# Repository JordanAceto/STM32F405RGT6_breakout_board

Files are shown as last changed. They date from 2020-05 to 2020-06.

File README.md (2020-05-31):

# Breakout board for STM32F405

## The goals of this project in no particular order:
- Get my feet wet with 4-layer pcb layout
- Try out the jlcpcb assembly service
- Get a few extra stm32 boards to experiment with

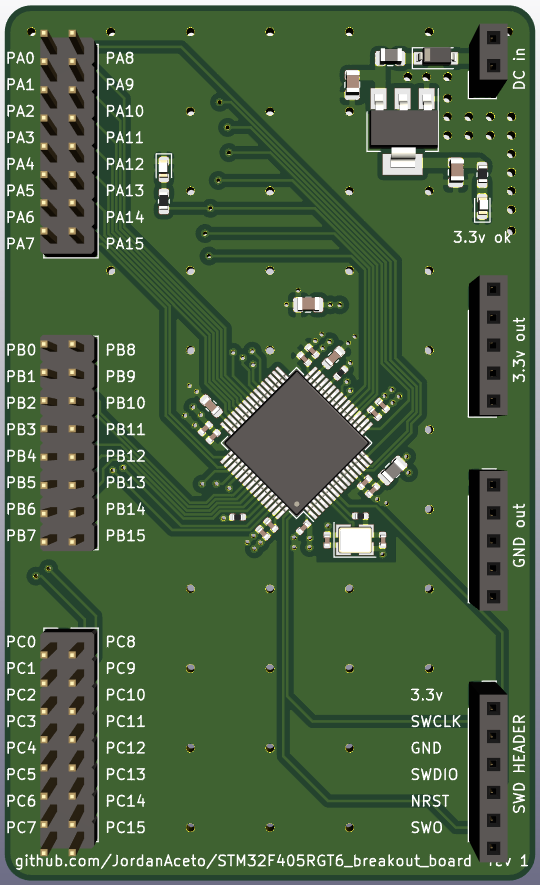
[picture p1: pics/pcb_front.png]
pcb front
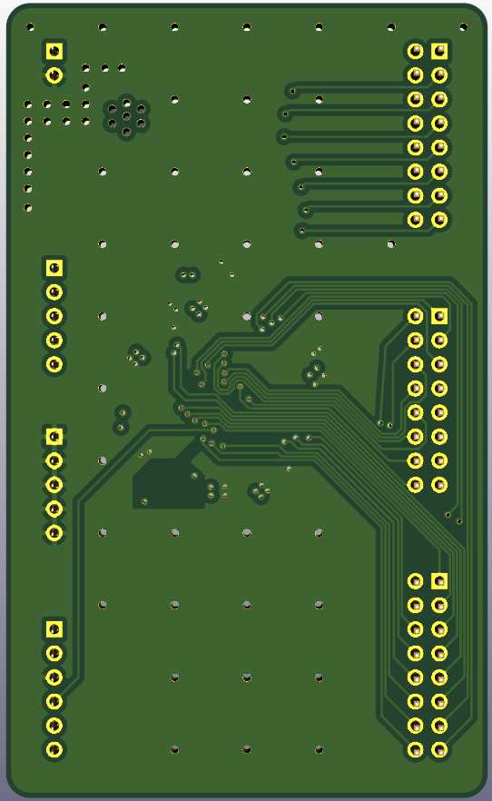
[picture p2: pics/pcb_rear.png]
pcb rear


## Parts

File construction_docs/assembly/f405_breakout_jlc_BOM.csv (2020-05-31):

Designator | Quantity | Value | Footprint | LCSC Part #
C1, C4, C8, | 3 | 10uF | 0805 | C15850
C2, C3, C6, C7, C9, C10, C11, C12, C13, C14, | 10 | 100nF | 0402 | C1525
C5, | 1 | 10nF | 0402 | C15195
C15, C16, | 2 | 2.2uF | 0603 | C23630
C17, C18, | 2 | 12pF | 0402 | C1547
D1, | 1 | B5819W | SOD-123 | C8598
D2, | 1 | power_LED | 0603 | C2286
D3, | 1 | user_LED | 0603 | C72043
FB1, FB2, | 2 | 100R @ 100MHz | 0805 | C1015
HSE1, | 1 | 16MHz | SMD-3225_4P | C13738
R1, R3, | 2 | 2k2 | 0603 | C4190
R2, R4, | 2 | 10k | 0402 | C25744
R5, | 1 | 100 | 0402 | C25076
U1, | 1 | AMS1117-3.3 | SOT-223 | C6186
U2, | 1 | STM32F405RGT6 | LQFP-64_10.0x10.0x0.5P | C15742

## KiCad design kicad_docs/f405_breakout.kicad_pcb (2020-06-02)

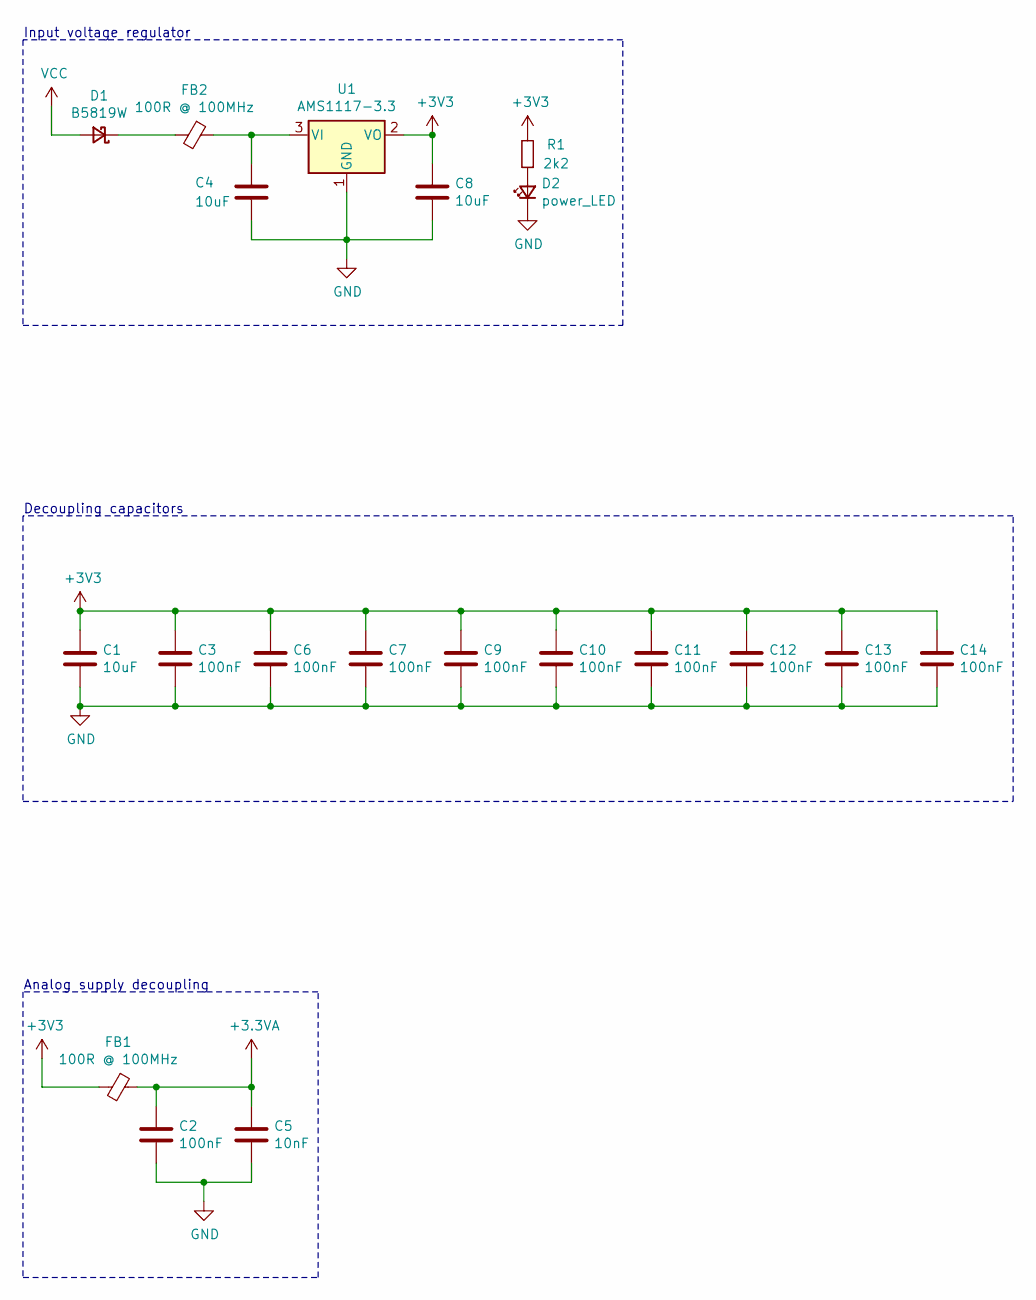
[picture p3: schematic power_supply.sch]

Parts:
C1, C4, C8: 10uF; C_0805_2012Metric
C2, C3, C6, C7, C9, C10, C11, C12, C13, C14: 100nF; C_0402_1005Metric
C5: 10nF; C_0402_1005Metric
D1: B5819W; D_SOD-123
D2: power_LED; LED_0603_1608Metric
FB1, FB2: 100R @ 100MHz; L_0805_2012Metric
R1: 2k2; R_0603_1608Metric
U1: AMS1117-3.3; SOT-223-3_TabPin2

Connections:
+3.3VA: C2.1, C5.1, FB1.1; also elsewhere on the board
+3V3: C1.1, C3.1, C6.1, C7.1, C8.1, C9.1, C10.1, C11.1, C12.1, C13.1, C14.1, FB1.2, R1.2, U1.2 (VO); also elsewhere on the board
GND: C1.2, C2.2, C3.2, C4.2, C5.2, C6.2, C7.2, C8.2, C9.2, C10.2, C11.2, C12.2, C13.2, C14.2, D2.1 (K), U1.1 (GND); also elsewhere on the board
unnamed: C4.1, FB2.1, U1.3 (VI)
unnamed: D1.1 (K), FB2.2
unnamed: D2.2 (A), R1.1
VCC: D1.2 (A); also elsewhere on the board

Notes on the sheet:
Input voltage regulator
Decoupling capacitors
Analog supply decoupling

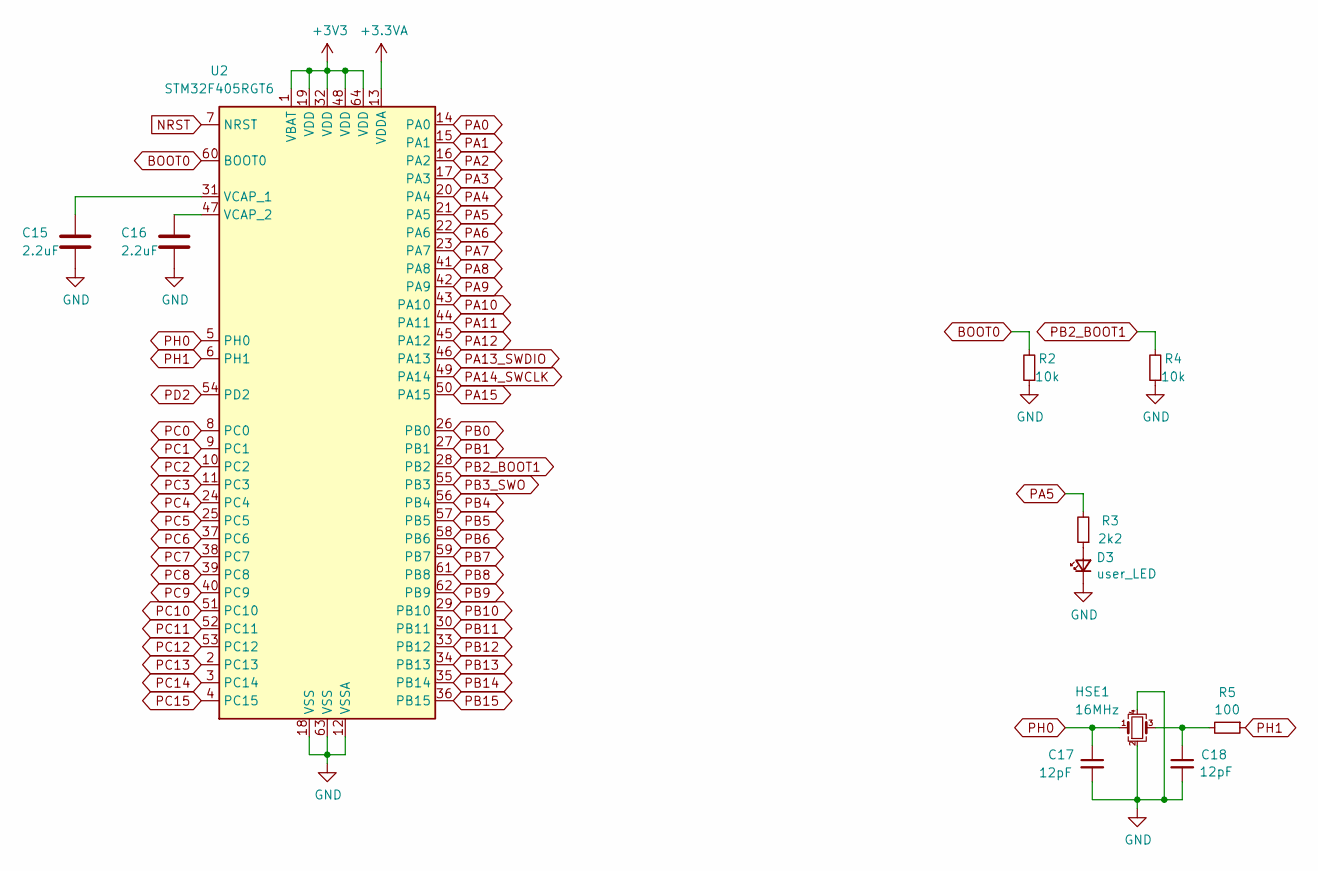
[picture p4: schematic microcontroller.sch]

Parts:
C15, C16: 2.2uF; C_0603_1608Metric
C17, C18: 12pF; C_0402_1005Metric
D3: user_LED; LED_0603_1608Metric
HSE1: 16MHz; Crystal_SMD_3225-4Pin_3.2x2.5mm
R2, R4: 10k; R_0402_1005Metric
R3: 2k2; R_0603_1608Metric
R5: 100; R_0402_1005Metric
U2: STM32F405RGT6; LQFP-64_10x10mm_P0.5mm

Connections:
+3.3VA: U2.13 (VDDA); also elsewhere on the board
+3V3: U2.1 (VBAT), U2.19 (VDD), U2.32 (VDD), U2.48 (VDD), U2.64 (VDD); also elsewhere on the board
BOOT0: R2.2, U2.60 (BOOT0)
GND: C15.2, C16.2, C17.2, C18.2, D3.1 (K), HSE1.2, HSE1.4, R2.1, R4.1, U2.12 (VSSA), U2.18 (VSS), U2.63 (VSS); also elsewhere on the board
NRST: U2.7 (NRST); also elsewhere on the board
unnamed: C15.1, U2.31 (VCAP_1)
unnamed: C16.1, U2.47 (VCAP_2)
unnamed: C18.1, HSE1.3, R5.2
unnamed: D3.2 (A), R3.1
PA0: U2.14 (PA0); also elsewhere on the board
PA1: U2.15 (PA1); also elsewhere on the board
PA2: U2.16 (PA2); also elsewhere on the board
PA3: U2.17 (PA3); also elsewhere on the board
PA4: U2.20 (PA4); also elsewhere on the board
PA5: R3.2, U2.21 (PA5); also elsewhere on the board
PA6: U2.22 (PA6); also elsewhere on the board
PA7: U2.23 (PA7); also elsewhere on the board
PA8: U2.41 (PA8); also elsewhere on the board
PA9: U2.42 (PA9); also elsewhere on the board
PA10: U2.43 (PA10); also elsewhere on the board
PA11: U2.44 (PA11); also elsewhere on the board
PA12: U2.45 (PA12); also elsewhere on the board
PA13_SWDIO: U2.46 (PA13); also elsewhere on the board
PA14_SWCLK: U2.49 (PA14); also elsewhere on the board
PA15: U2.50 (PA15); also elsewhere on the board
PB0: U2.26 (PB0); also elsewhere on the board
PB1: U2.27 (PB1); also elsewhere on the board
PB2_BOOT1: R4.2, U2.28 (PB2); also elsewhere on the board
PB3_SWO: U2.55 (PB3); also elsewhere on the board
PB4: U2.56 (PB4); also elsewhere on the board
PB5: U2.57 (PB5); also elsewhere on the board
PB6: U2.58 (PB6); also elsewhere on the board
PB7: U2.59 (PB7); also elsewhere on the board
PB8: U2.61 (PB8); also elsewhere on the board
PB9: U2.62 (PB9); also elsewhere on the board
PB10: U2.29 (PB10); also elsewhere on the board
PB11: U2.30 (PB11); also elsewhere on the board
PB12: U2.33 (PB12); also elsewhere on the board
PB13: U2.34 (PB13); also elsewhere on the board
PB14: U2.35 (PB14); also elsewhere on the board
PB15: U2.36 (PB15); also elsewhere on the board
PC0: U2.8 (PC0); also elsewhere on the board
PC1: U2.9 (PC1); also elsewhere on the board
PC2: U2.10 (PC2); also elsewhere on the board
PC3: U2.11 (PC3); also elsewhere on the board
PC4: U2.24 (PC4); also elsewhere on the board
PC5: U2.25 (PC5); also elsewhere on the board
PC6: U2.37 (PC6); also elsewhere on the board
PC7: U2.38 (PC7); also elsewhere on the board
PC8: U2.39 (PC8); also elsewhere on the board
PC9: U2.40 (PC9); also elsewhere on the board
PC10: U2.51 (PC10); also elsewhere on the board
PC11: U2.52 (PC11); also elsewhere on the board
PC12: U2.53 (PC12); also elsewhere on the board
PC13: U2.2 (PC13); also elsewhere on the board
PC14: U2.3 (PC14); also elsewhere on the board
PC15: U2.4 (PC15); also elsewhere on the board
PD2: U2.54 (PD2)
PH0: C17.1, HSE1.1, U2.5 (PH0)
PH1: R5.1, U2.6 (PH1)

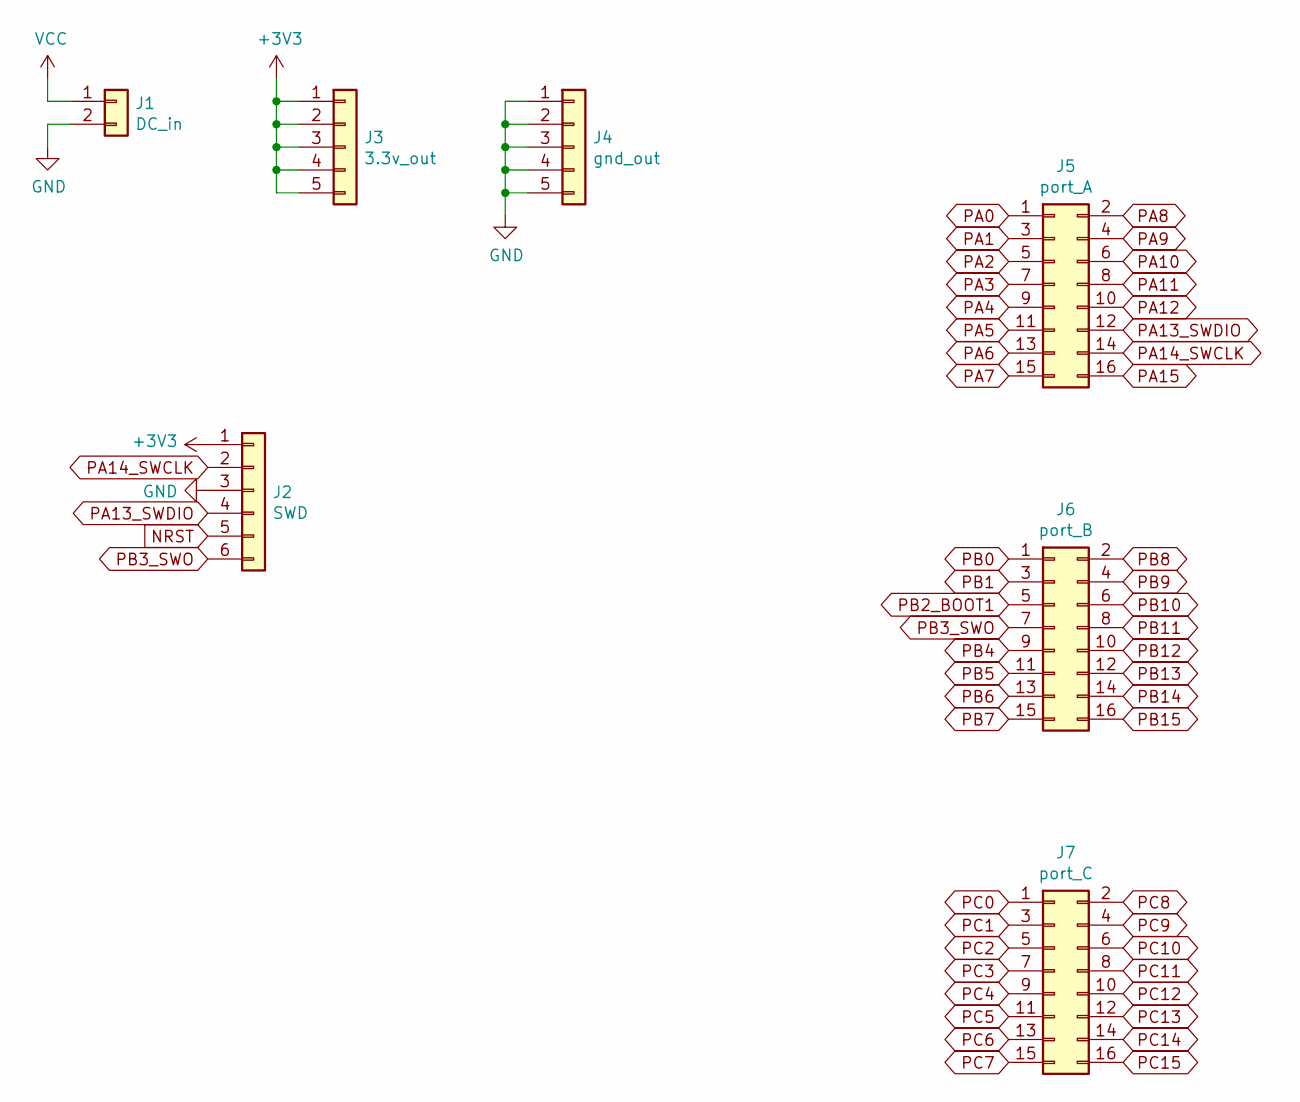
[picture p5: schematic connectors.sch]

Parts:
J1: DC_in; PinSocket_1x02_P2.54mm_Vertical
J2: SWD; PinSocket_1x06_P2.54mm_Vertical
J3: 3.3v_out; PinSocket_1x05_P2.54mm_Vertical
J4: gnd_out; PinSocket_1x05_P2.54mm_Vertical
J5: port_A; PinHeader_2x08_P2.54mm_Vertical
J6: port_B; PinHeader_2x08_P2.54mm_Vertical
J7: port_C; PinHeader_2x08_P2.54mm_Vertical

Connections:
+3V3: J2.1, J3.1, J3.2, J3.3, J3.4, J3.5; also elsewhere on the board
GND: J1.2, J2.3, J4.1, J4.2, J4.3, J4.4, J4.5; also elsewhere on the board
NRST: J2.5; also elsewhere on the board
PA0: J5.1; also elsewhere on the board
PA1: J5.3; also elsewhere on the board
PA2: J5.5; also elsewhere on the board
PA3: J5.7; also elsewhere on the board
PA4: J5.9; also elsewhere on the board
PA5: J5.11; also elsewhere on the board
PA6: J5.13; also elsewhere on the board
PA7: J5.15; also elsewhere on the board
PA8: J5.2; also elsewhere on the board
PA9: J5.4; also elsewhere on the board
PA10: J5.6; also elsewhere on the board
PA11: J5.8; also elsewhere on the board
PA12: J5.10; also elsewhere on the board
PA13_SWDIO: J2.4, J5.12; also elsewhere on the board
PA14_SWCLK: J2.2, J5.14; also elsewhere on the board
PA15: J5.16; also elsewhere on the board
PB0: J6.1; also elsewhere on the board
PB1: J6.3; also elsewhere on the board
PB2_BOOT1: J6.5; also elsewhere on the board
PB3_SWO: J2.6, J6.7; also elsewhere on the board
PB4: J6.9; also elsewhere on the board
PB5: J6.11; also elsewhere on the board
PB6: J6.13; also elsewhere on the board
PB7: J6.15; also elsewhere on the board
PB8: J6.2; also elsewhere on the board
PB9: J6.4; also elsewhere on the board
PB10: J6.6; also elsewhere on the board
PB11: J6.8; also elsewhere on the board
PB12: J6.10; also elsewhere on the board
PB13: J6.12; also elsewhere on the board
PB14: J6.14; also elsewhere on the board
PB15: J6.16; also elsewhere on the board
PC0: J7.1; also elsewhere on the board
PC1: J7.3; also elsewhere on the board
PC2: J7.5; also elsewhere on the board
PC3: J7.7; also elsewhere on the board
PC4: J7.9; also elsewhere on the board
PC5: J7.11; also elsewhere on the board
PC6: J7.13; also elsewhere on the board
PC7: J7.15; also elsewhere on the board
PC8: J7.2; also elsewhere on the board
PC9: J7.4; also elsewhere on the board
PC10: J7.6; also elsewhere on the board
PC11: J7.8; also elsewhere on the board
PC12: J7.10; also elsewhere on the board
PC13: J7.12; also elsewhere on the board
PC14: J7.14; also elsewhere on the board
PC15: J7.16; also elsewhere on the board
VCC: J1.1; also elsewhere on the board

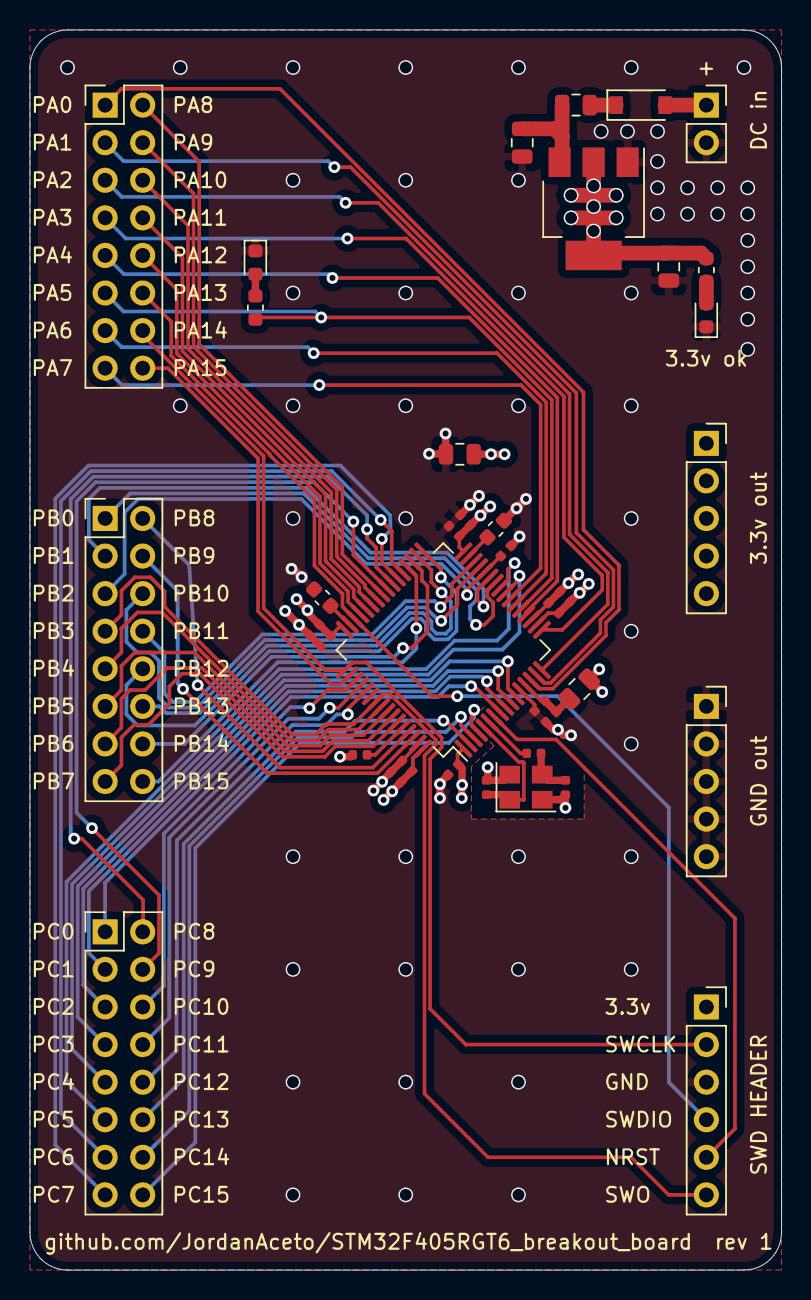
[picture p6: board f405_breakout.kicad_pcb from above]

Board: 4 copper layers, 50.8 x 83.8 mm, 38 parts (0 on the bottom side), 63 nets.

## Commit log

2020-05-31 initial commit(2)
    [connectors.sch, f405_breakout.kicad_pcb, f405_breakout.sch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]
2020-05-31 add git url to silkscreen
    [f405_breakout.kicad_pcb]
2020-05-31 create gerbers and assembly files
    [f405_breakout-3_3V.gbr, f405_breakout-B_Cu.gbr, f405_breakout-Edge_Cuts.gbr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]
2020-05-31 add pcb pics
2020-05-31 add pdf schematic
2020-06-02 fix gerber problem, add bottom mask
    [f405_breakout-3_3V.gbr, f405_breakout-B_Cu.gbr, f405_breakout-B_Mask.gbr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]
